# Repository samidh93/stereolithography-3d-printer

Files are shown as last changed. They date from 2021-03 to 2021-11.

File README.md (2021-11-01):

# stereolithography 3d printer

## description

SLA 3d printer was created and developped during this project.
The main goal is to print a cylindre using a resonant laser system.
in this repo you will find:
- software stack written in c on stm32 microcontroller [main](/Src/main.c)
- pcb designed with eagle [pcb](pcb_eagle/)
- documentation and contributions [report](3D%20Drucker_Reser12_V5.pdf)

## Picture from inside the printer 
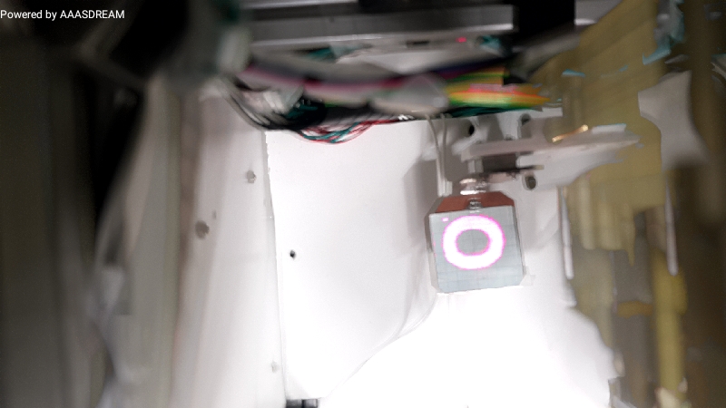
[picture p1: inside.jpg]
inside


## picture from outside the printer
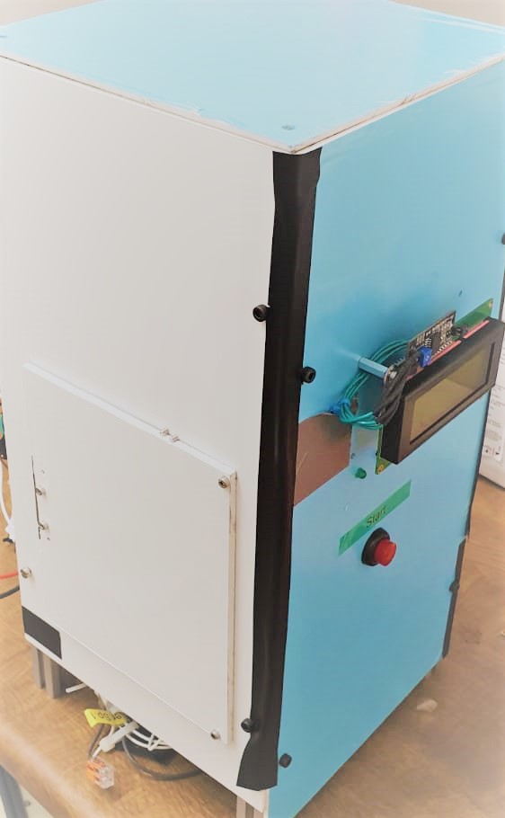
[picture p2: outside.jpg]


## demonstartion of running
running demo

[running mp4 ideo with sound](running.mp4)

## demonstartion of printing
printing demo

[printing mp4 video with sound](printing.mp4)

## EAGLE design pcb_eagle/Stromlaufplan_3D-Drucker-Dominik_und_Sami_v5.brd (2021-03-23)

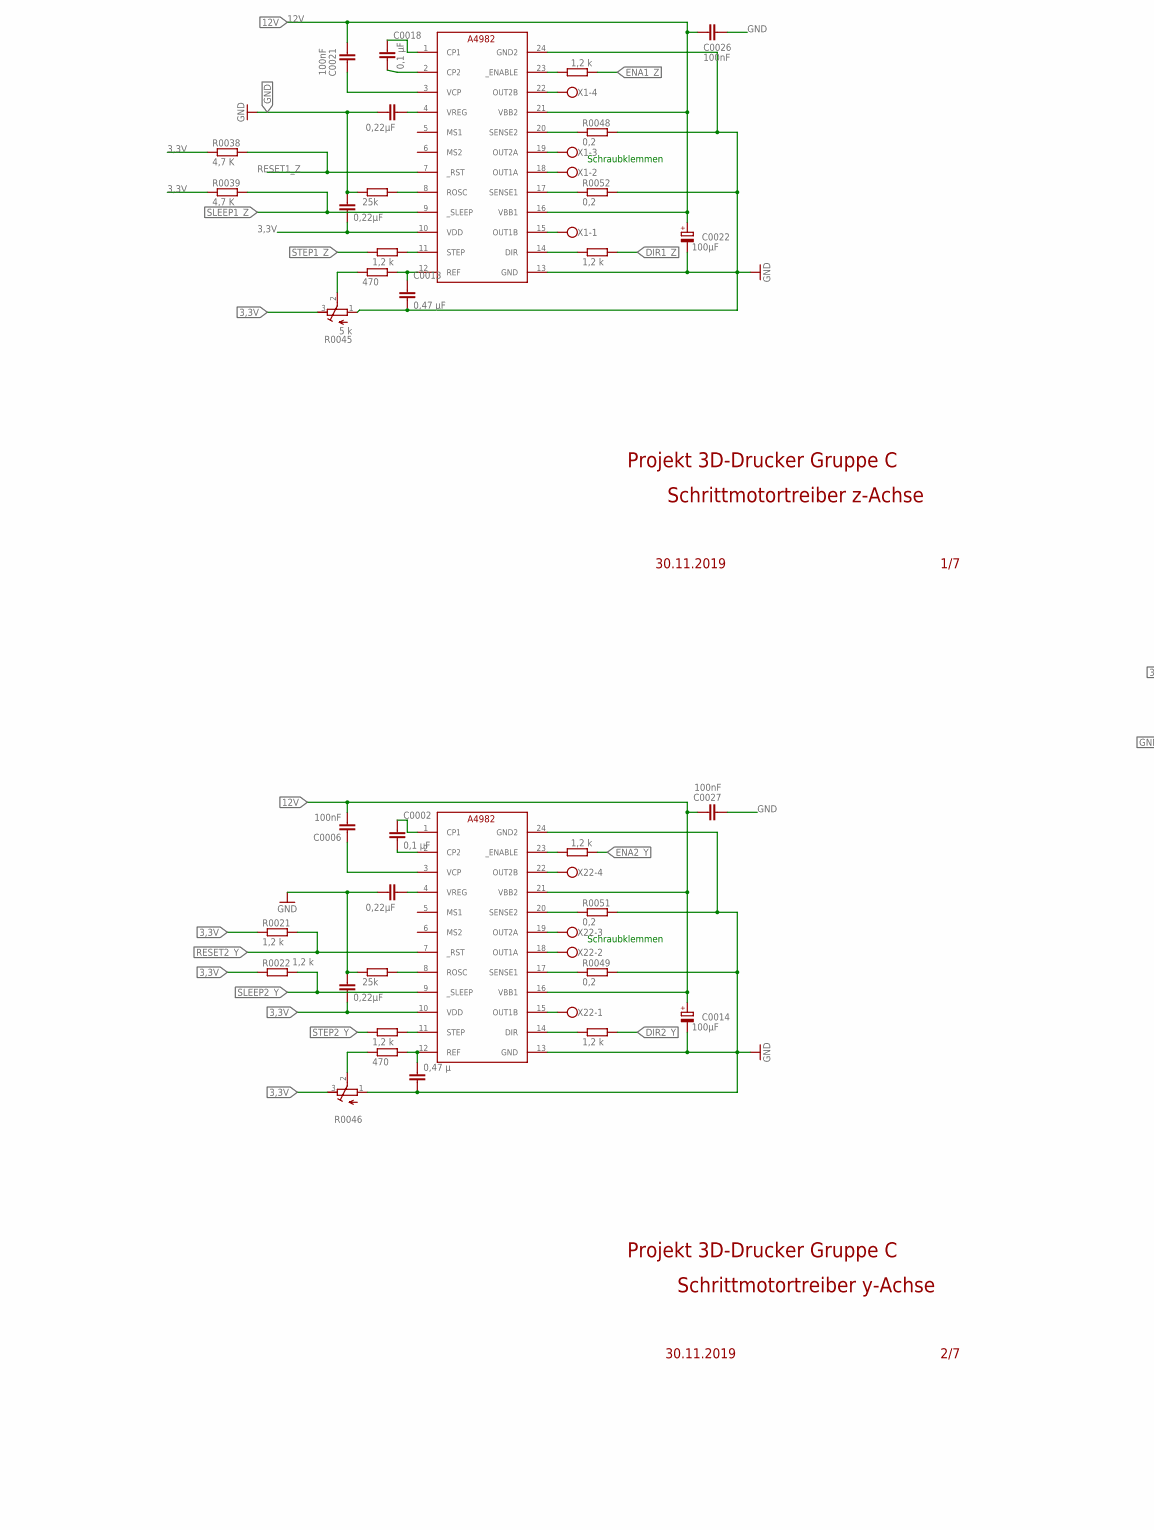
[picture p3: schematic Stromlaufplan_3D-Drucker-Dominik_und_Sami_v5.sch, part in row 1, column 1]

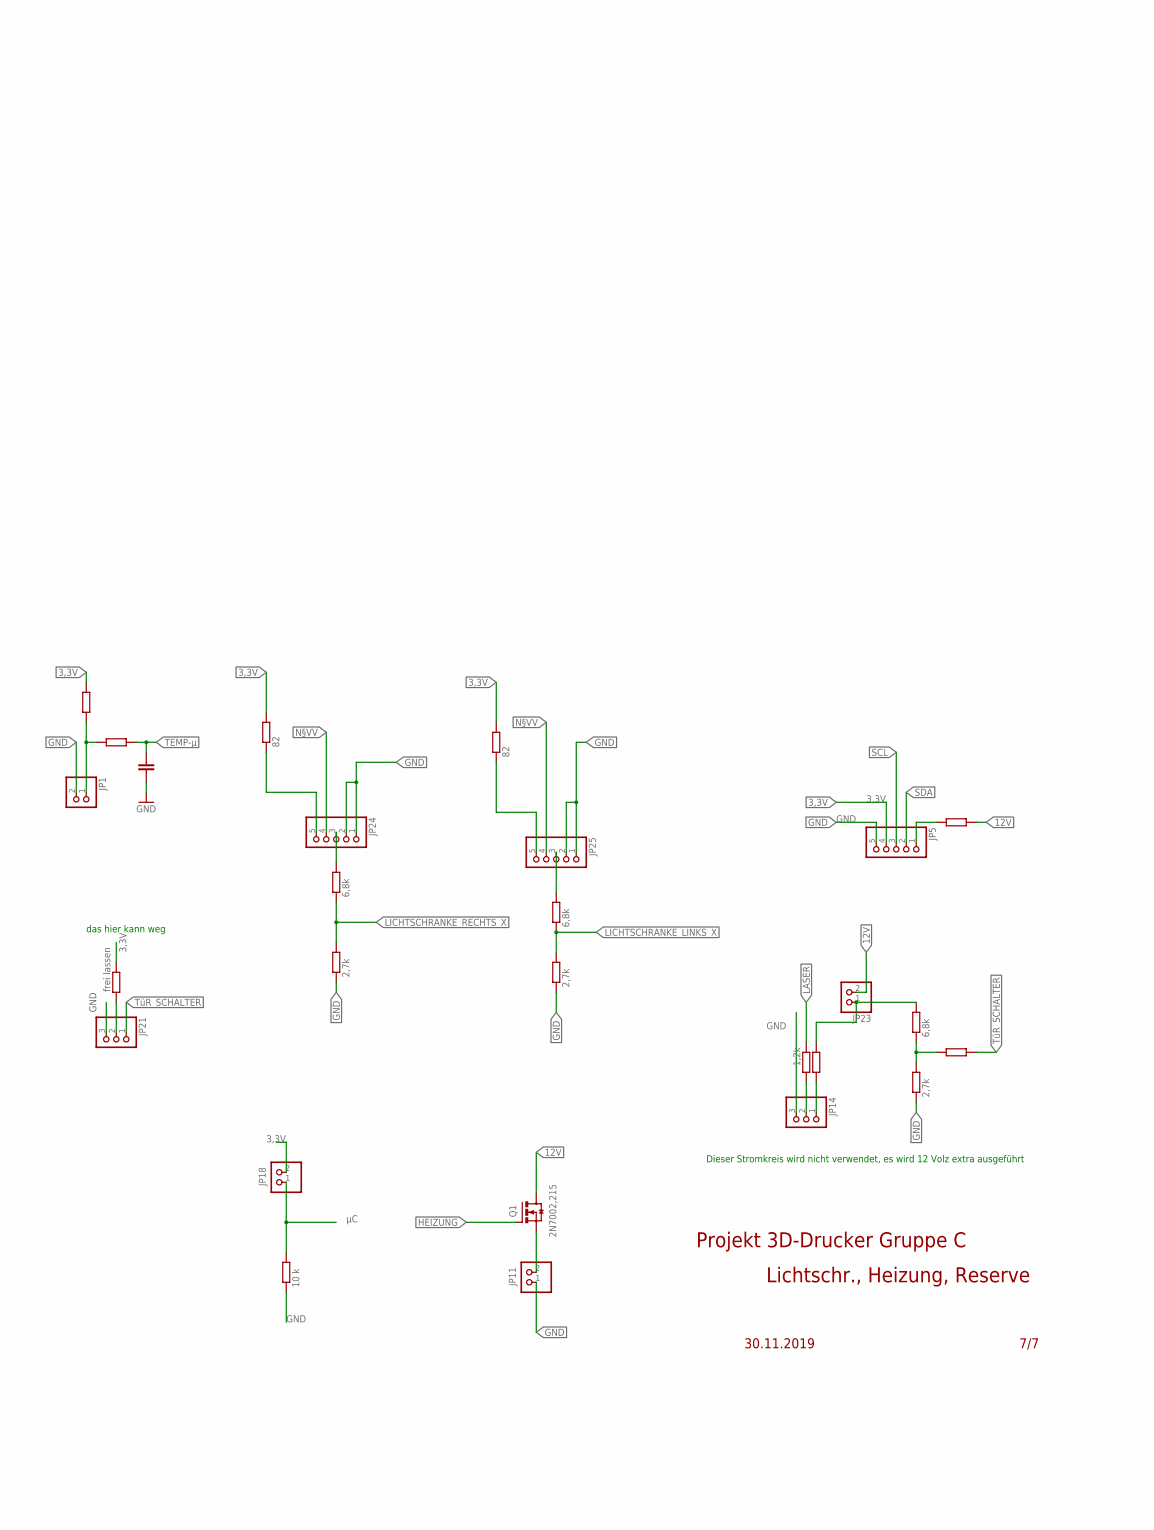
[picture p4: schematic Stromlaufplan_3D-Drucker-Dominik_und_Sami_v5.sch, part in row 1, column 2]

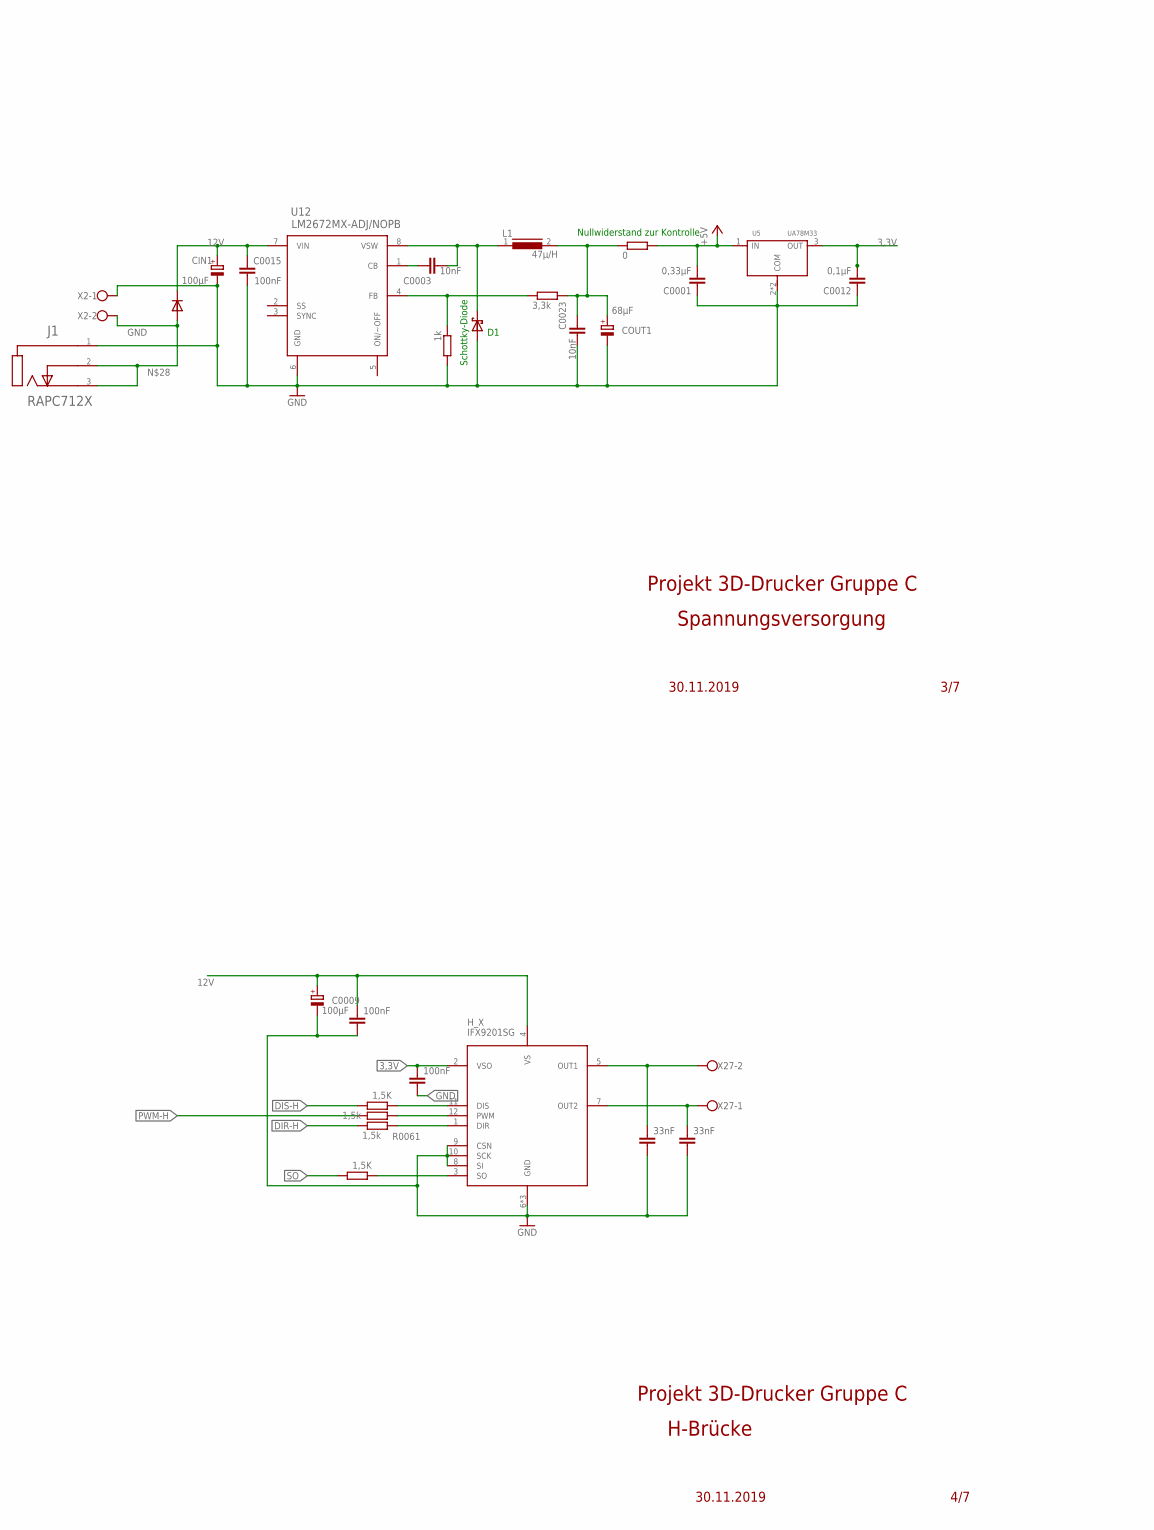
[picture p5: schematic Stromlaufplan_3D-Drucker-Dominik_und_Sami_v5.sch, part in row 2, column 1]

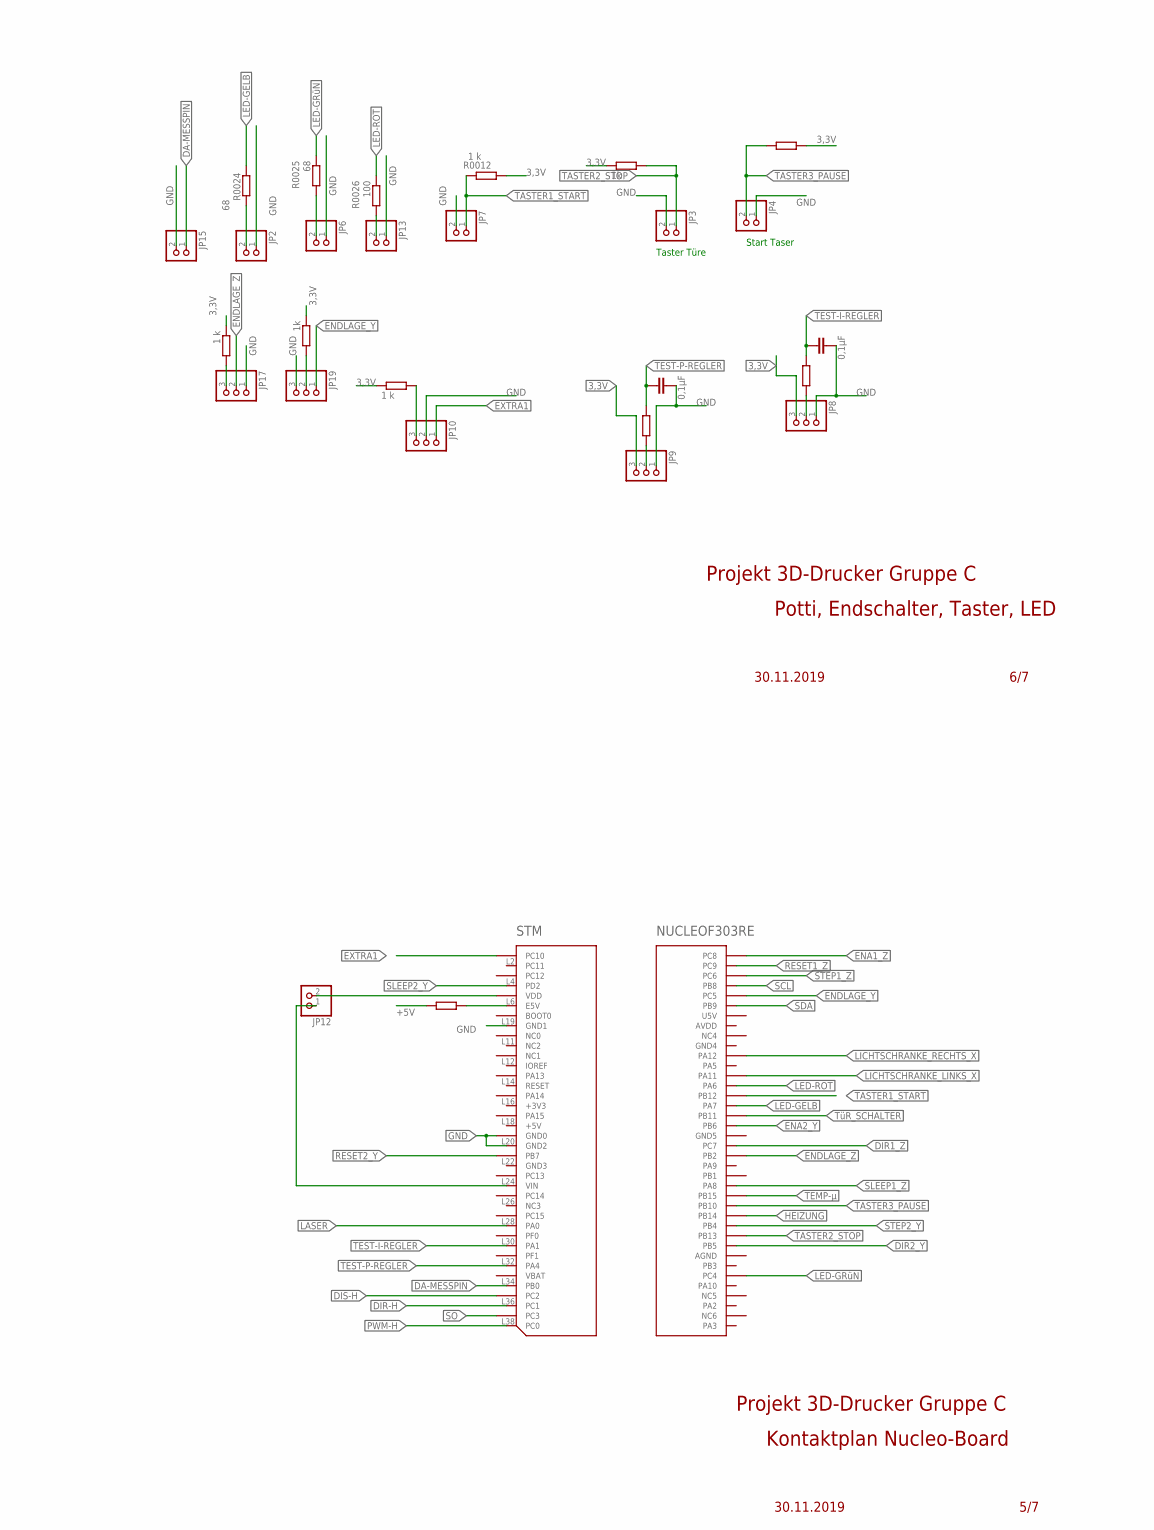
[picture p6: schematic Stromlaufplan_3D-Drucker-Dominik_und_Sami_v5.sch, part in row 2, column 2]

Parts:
A4982_Y, A4982_Y1: A4982_STEPDRIVER; TSSOP24
C0001: 0,33µF; C0603
C0002, C0018: 0,1 µF; C0603
C0003, C0023: 10nF; C0603
C0004, C0005, C0019, C0020: 0,22µF; C0603
C0006, C0015, C0021, C0026, C0027: 100nF; C0603
C0007, C0008: 33nF; C0805
C0009, C0014, C0022: 100µF; UD-8X10_NICHICON
C0010: 0,47 µ; C0805
C0011: C-EUC0805; C0805
C0012, C0024, C0025: 0,1µF; C0603
C0013: 0,47 µF; C0603
C0016, C0041: 100nF; C0805
CIN1: 100µF; 140CLH-1010
COUT1: 68µF; 140CLH-1010
D1: 1N5819HW-7-F; SOD-123_MINI-SMA
D12: MURS360BT3G; SMB
H_X: IFX9201SG; BSOP-12
J1: RAPC712X; SWC_RAPC712X
JP1, JP2, JP3, JP4, JP6, JP7, JP11, JP12, JP13, JP15, JP18, JP23: PINHD-1X2; 1X02
JP5, JP24, JP25: PINHD-1X5; 1X05
JP8, JP9, JP10, JP14, JP17, JP19, JP21: PINHD-1X3; 1X03
L1: 47µ/H; INDUCTOR
Q1: 2N7002,215; SOT23-3
R0001, R0063: 1,5K; R0603
R0002, R0005, R0043: 6,8k; R0603
R0003, R0013: 1k; R0603
R0004, R0028, R0044: 2,7k; R0603
R0006, R0019: 25k; R0603
R0007: 10 k; R0603
R0008, R0014, R0016, R0017, R0020, R0027, R0030, R0031, R0053: R-EU_R0603; R0603
R0009, R0010, R0011, R0021, R0022, R0034, R0035, R0036: 1,2 k; R0603
R0012, R0015, R0033: 1 k; R0603
R0018: frei lassen; R0603
R0023, R0037: 470; R0603
R0024, R0025: 68; R0603
R0026: 100; R0603
R0029, R0032: 82; R0603
R0038, R0039: 4,7 K; R0603
R0042: 1,2k; R0603
R0045: 5 k; RTRIM3296Y
R0046: R-TRIMM3296Y; RTRIM3296Y
R0048, R0049, R0051, R0052: 0,2; R2512
R0061, R0062: 1,5k; R0603
STM: NUCLEOF303RE; DIL40
TEST_R: 0; R0603
TEST_R2: 3,3k; R0603
TEST_R3: 1k; R0603
U5: UA78M33; SOT-223
U12: LM2672MX-ADJ/NOPB; SOIC-8
X1, X22: SCHRAUBKLEMME_4X; W237-4
X2, X27: SCHRAUBKLEMME_2X; W237-102

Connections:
3,3V: A4982_Y.10 (VDD), A4982_Y1.10 (VDD), C0005.1, C0012.2, C0016.1, C0020.1, H_X.2 (VSO), JP5.4, JP8.3, JP9.3, JP18.2, R0003.1, R0008.1, R0012.1, R0013.1, R0014.1, R0015.1, R0018.1, R0021.1, R0022.1, R0029.2, R0032.2, R0033.1, R0038.1, R0039.1, R0045.3 (E), R0046.3 (E), U5.3 (OUT)
12V: A4982_Y.16 (VBB1), A4982_Y.21 (VBB2), A4982_Y1.16 (VBB1), A4982_Y1.21 (VBB2), C0006.2, C0009.+, C0014.+, C0015.2, C0021.2, C0022.+, C0026.2, C0027.1, C0041.1, CIN1.+, D12.1, H_X.4 (VS), JP14.1, JP23.2, Q1.3 (D), R0016.2, R0030.2, U12.7 (VIN)
+5V: C0001.2, R0027.1, TEST_R.2, U5.1 (IN)
DA-MESSPIN: JP15.1, STM.L34 (PB0)
DIR1_Z: R0036.2, STM.R19 (PC7)
DIR2_Y: R0011.2, STM.R29 (PB5)
DIR-H: R0061.1, STM.L36 (PC1)
DIS-H: R0063.1, STM.L35 (PC2)
ENA1_Z: R0034.1, STM.R2 (PC8)
ENA2_Y: R0009.1, STM.R17 (PB6)
ENDLAGE_Y: JP19.1, STM.R6 (PC5)
ENDLAGE_Z: JP17.2, STM.R22 (PB2)
EXTRA1: JP10.1, STM.L1 (PC10)
GND: A4982_Y.13 (GND), A4982_Y.24 (GND2), A4982_Y1.13 (GND), A4982_Y1.24 (GND2), C0001.1, C0004.2, C0005.2, C0007.2, C0008.2, C0009.-, C0010.2, C0011.2, C0012.1, C0013.2, C0014.-, C0015.1, C0016.2, C0019.2, C0020.2, C0022.-, C0023.2, C0024.1, C0025.1, C0026.1, C0027.2, C0041.2, CIN1.-, COUT1.-, D1.A, H_X.6 (GND), H_X.8 (SI), H_X.9 (CSN), H_X.10 (SCK), H_X.PAD (GND), H_X.PAD2 (GND), J1.1 (CENTER_PIN), JP1.2, JP2.1, JP3.2, JP4.1, JP5.5, JP6.1, JP7.2, JP8.1, JP9.1, JP10.2, JP11.1, JP13.1, JP14.3, JP15.2, JP17.1, JP19.3, JP21.3, JP24.1, JP24.2, JP25.1, JP25.2, R0004.1, R0006.1, R0007.1, R0019.1, R0028.1, R0044.1, R0045.1 (A), R0046.1 (A), R0048.2, R0049.2, R0051.2, R0052.2, STM.L8 (GND0), STM.L19 (GND1), STM.L20 (GND2), TEST_R3.2, U5.2 (COM), U5.TER (COM), U12.6 (GND), X2.1
HEIZUNG: Q1.1 (G), STM.R28 (PB14)
LASER: R0042.1, STM.L28 (PA0)
LED-GELB: R0024.2, STM.R15 (PA7)
LED-GRüN: R0025.1, STM.R34 (PC4)
LED-ROT: R0026.1, STM.R13 (PA6)
LICHTSCHRANKE_LINKS_X: R0005.1, R0028.2, STM.R14 (PA11)
LICHTSCHRANKE_RECHTS_X: R0002.1, R0004.2, STM.R12 (PA12)
unnamed: A4982_Y1.2 (CP2), C0018.2
unnamed: JP17.3, R0015.2
unnamed: JP24.5, R0029.1
unnamed: R0023.1, R0046.2 (S)
unnamed: C0003.1, U12.1 (CB)
unnamed: JP2.2, R0024.1
unnamed: A4982_Y.12 (REF), C0010.1, R0023.2
unnamed: A4982_Y.2 (CP2), C0002.2
unnamed: A4982_Y.1 (CP1), C0002.1
unnamed: A4982_Y.3 (VCP), C0006.1
unnamed: JP19.2, R0003.2
unnamed: A4982_Y.4 (VREG), C0004.1
unnamed: A4982_Y1.12 (REF), C0013.1, R0037.2
unnamed: A4982_Y1.1 (CP1), C0018.1
unnamed: A4982_Y.18 (OUT1A), X22.2
unnamed: A4982_Y.15 (OUT1B), X22.1
unnamed: A4982_Y.19 (OUT2A), X22.3
unnamed: A4982_Y.22 (OUT2B), X22.4
unnamed: A4982_Y.17 (SENSE1), R0049.1
unnamed: A4982_Y.20 (SENSE2), R0051.1
unnamed: A4982_Y.8 (ROSC), R0006.2
unnamed: A4982_Y.23 (_ENABLE), R0009.2
unnamed: H_X.3 (SO), R0001.2
unnamed: A4982_Y.14 (DIR), R0011.1
unnamed: A4982_Y1.4 (VREG), C0019.1
unnamed: A4982_Y1.15 (OUT1B), X1.1
unnamed: JP23.1, R0016.1, R0043.2
unnamed: D12.2, J1.2 (SHUNT), J1.3 (SLEEVE), X2.2
unnamed: C0023.1, COUT1.+, L1.2, TEST_R.1, TEST_R2.2
unnamed: A4982_Y1.19 (OUT2A), X1.3
unnamed: C0003.2, D1.C, L1.1, U12.8 (VSW)
unnamed: JP9.2, R0031.1
unnamed: JP24.3, R0002.2
unnamed: JP25.3, R0005.2
unnamed: R0017.1, R0043.1, R0044.2
unnamed: JP8.2, R0053.1
unnamed: A4982_Y1.22 (OUT2B), X1.4
unnamed: JP11.2, Q1.2 (S)
unnamed: A4982_Y1.17 (SENSE1), R0052.1
unnamed: JP6.2, R0025.2
unnamed: JP13.2, R0026.2
unnamed: A4982_Y1.20 (SENSE2), R0048.1
unnamed: A4982_Y1.8 (ROSC), R0019.2
unnamed: A4982_Y1.23 (_ENABLE), R0034.2
unnamed: H_X.1 (DIR), R0061.2
unnamed: H_X.12 (PWM), R0062.2
unnamed: C0007.1, H_X.5 (OUT1), X27.2
unnamed: JP5.1, R0030.1
unnamed: A4982_Y1.14 (DIR), R0036.1
unnamed: JP25.5, R0032.1
unnamed: JP10.3, R0033.2
unnamed: JP14.2, R0042.2
unnamed: JP1.1, R0008.2, R0020.2
unnamed: A4982_Y1.18 (OUT1A), X1.2
unnamed: A4982_Y1.3 (VCP), C0021.1
unnamed: JP12.2, STM.L5 (VDD)
unnamed: R0037.1, R0045.2 (S)
unnamed: JP12.1, STM.L24 (VIN)
unnamed: R0027.2, STM.L6 (E5V)
unnamed: JP21.2, R0018.2
unnamed: H_X.11 (DIS), R0063.2
unnamed: C0008.1, H_X.7 (OUT2), X27.1
N§VV: JP24.4, JP25.4, TEST_R2.1, TEST_R3.1, U12.4 (FB)
PWM-H: R0062.1, STM.L38 (PC0)
RESET1_Z: A4982_Y1.7 (_RST), R0038.2, STM.R1 (PC9)
RESET2_Y: A4982_Y.7 (_RST), R0021.2, STM.L21 (PB7)
SCL: JP5.3, STM.R3 (PB8)
SDA: JP5.2, STM.R5 (PB9)
SLEEP1_Z: A4982_Y1.9 (_SLEEP), R0039.2, STM.R23 (PA8)
SLEEP2_Y: A4982_Y.9 (_SLEEP), R0022.2, STM.L4 (PD2)
SO: R0001.1, STM.L37 (PC3)
STEP1_Z: R0035.1, STM.R4 (PC6)
STEP2_Y: R0010.1, STM.R27 (PB4)
STP1: A4982_Y.11 (STEP), R0010.2
STP2: A4982_Y1.11 (STEP), R0035.2
TASTER1_START: JP7.1, R0012.2, STM.R16 (PB12)
TASTER2_STOP: JP3.1, R0013.2, STM.R30 (PB13)
TASTER3_PAUSE: JP4.2, R0014.2, STM.R25 (PB10)
TEMP-µ: C0011.1, R0020.1, STM.R26 (PB15)
TEST-I-REGLER: C0025.2, R0053.2, STM.L30 (PA1)
TEST-P-REGLER: C0024.2, R0031.2, STM.L32 (PA4)
TüR_SCHALTER: JP21.1, R0017.2, STM.R18 (PB11)
µC: JP18.1, R0007.2

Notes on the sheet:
Nullwiderstand zur Kontrolle
Schraubklemmen
das hier kann weg
Schottky-Diode
Dieser Stromkreis wird nicht verwendet, es wird 12 Volz extra ausgeführt
Start Taser
Taster Türe
Schrittmotortreiber z-Achse
1/7
Schrittmotortreiber y-Achse
Spannungsversorgung
H-Brücke
Kontaktplan Nucleo-Board
Potti, Endschalter, Taster, LED
Lichtschr., Heizung, Reserve
2/7
3/7
5/7
6/7
7/7
4/7
Projekt 3D-Drucker Gruppe C
30.11.2019

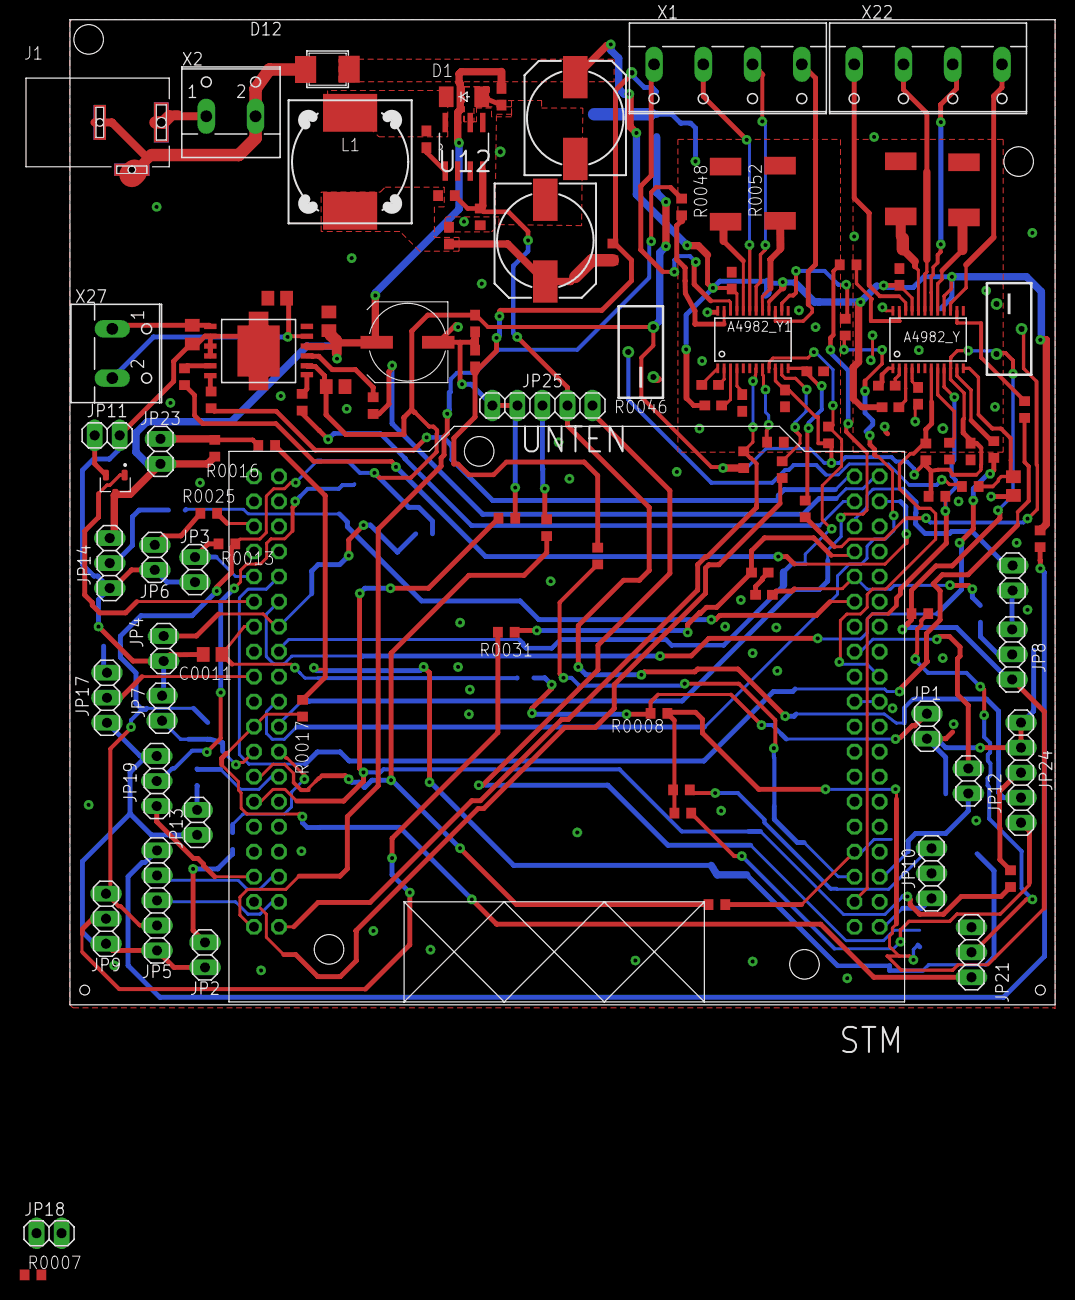
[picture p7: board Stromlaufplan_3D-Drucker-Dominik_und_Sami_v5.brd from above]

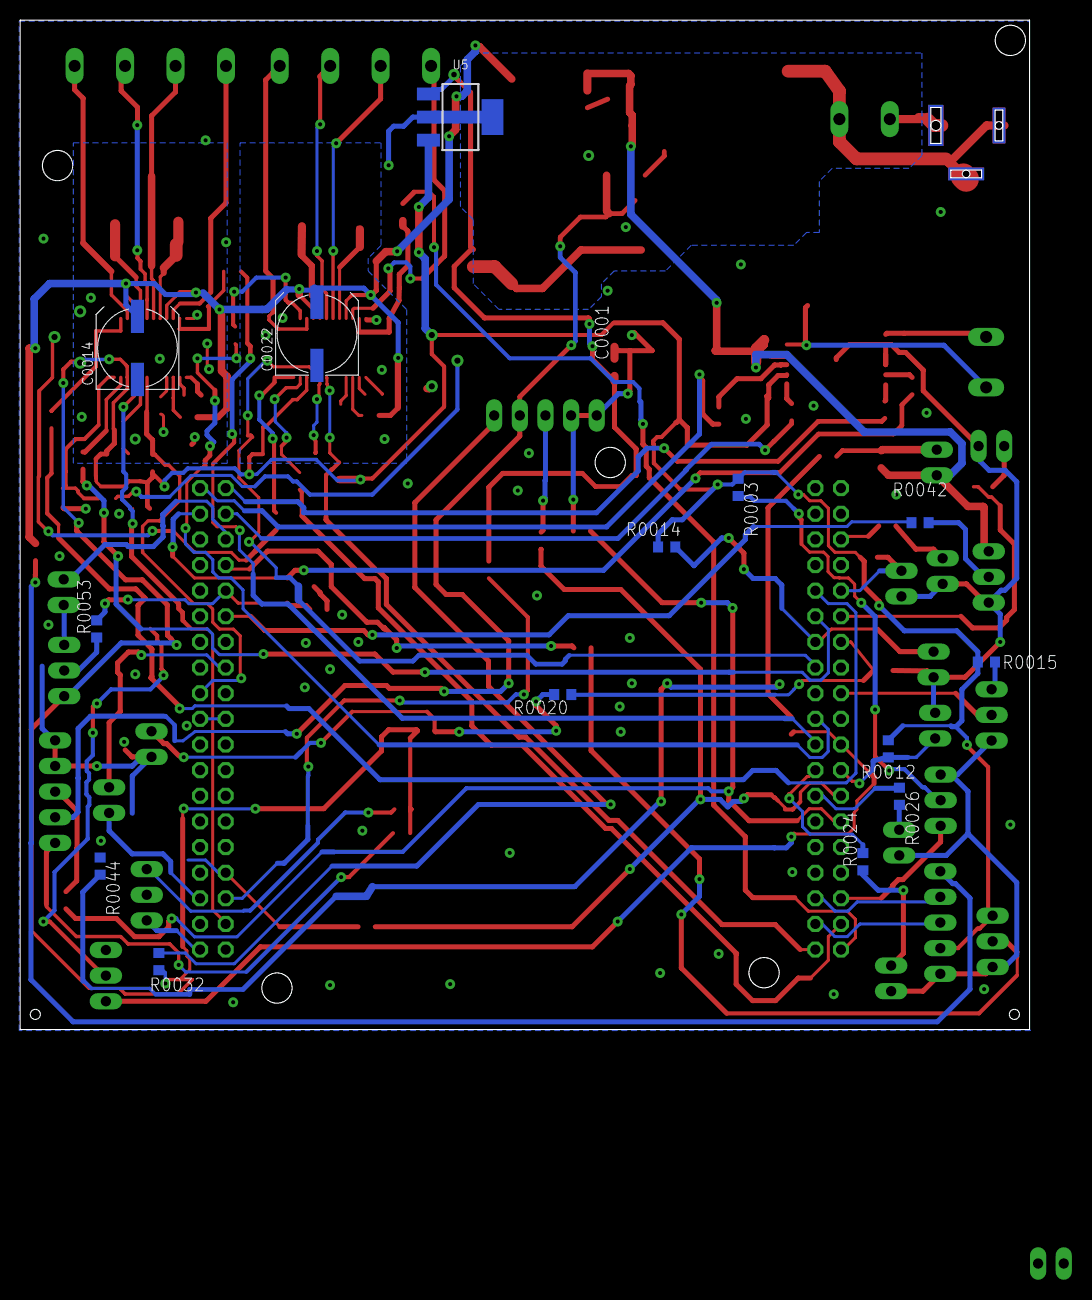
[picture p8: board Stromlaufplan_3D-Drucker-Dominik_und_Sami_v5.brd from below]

Board: 2 copper layers, 100.0 x 100.0 mm, 121 parts (14 on the bottom side), 104 nets.

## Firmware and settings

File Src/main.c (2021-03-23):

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

/* Includes ------------------------------------------------------------------*/
#include "main.h"

/* USER CODE BEGIN Includes */

#include "stdio.h"
#include "stdlib.h"
#include "math.h"						//Include math bibliothek
#include "SchrittMotor_Y.h"				//Bibliothek der treiber Y_achse
#include "SchrittMotor_Z.h"				//Bibliothek der treiber Z_achse
#include "print_scan_usart2.h"			//Bibliothek zur ausgabe von werte durch printf via uart
#include "i2c-lcd.h"					//Dispaly Bibliothek
#include "IIR_1_Order.h"				//IIR filetr bibliothek
//#include "Delay_Mikro_Sekunde.h"

/* USER CODE END Includes */

/* USER CODE BEGIN PTD */
typedef enum { Start, Init, Drucken, Ende} States_t;
/* USER CODE END PTD */

ADC_HandleTypeDef hadc1;
ADC_HandleTypeDef hadc2;
ADC_HandleTypeDef hadc3;
ADC_HandleTypeDef hadc4;
DMA_HandleTypeDef hdma_adc4;

I2C_HandleTypeDef hi2c1;

TIM_HandleTypeDef htim1;
TIM_HandleTypeDef htim2;
TIM_HandleTypeDef htim3;
TIM_HandleTypeDef htim4;
TIM_HandleTypeDef htim6;
TIM_HandleTypeDef htim7;
TIM_HandleTypeDef htim8;
TIM_HandleTypeDef htim15;
TIM_HandleTypeDef htim16;
TIM_HandleTypeDef htim17;

UART_HandleTypeDef huart2;

/* USER CODE BEGIN PV */
/******************************************************************
 * *************************User_Variablen*************************
 * ****************************************************************/

/*******************************Variablen Sinus Tabelle*************************/
float pi = 3.1416f;						// Variable pi
float sinus [128];						// Array für Sinustabelle
float ZeitProSchwingung;				//zeit für 1 schwingung
float remainTime;						//verbleibende zeit
/**************************Zeit variablen Lichtschranke***************************/
volatile float t_1 = 0;						// Zeitpunkt erste fallende Flanke
volatile float t_2 = 0;						// Zeitpunkt zweite steigende Flanke
volatile float t_3 = 0;						// Zeitpunkt zweite fallende Flanke
volatile float t_4 = 0;						// Zeitpunkt dritte steigende Flanke
volatile float hell_1 = 0;					// bereich in dem wir belichten 1/3 der zeit(_1 bedeutet fur halbe schwingung nach rechts)
volatile float hell_2 = 0;					// bereich in dem wir belichten 1/3 der zeit(_2 bedeutet fur halbe schwingung nach links)
volatile float dunkel_1 = 0;					// bereich in dem wir nicht belichten(_1 bedeutet fur halbe schwingung nach rechts)
volatile float dunkel_2 = 0;					// bereich in dem wir nicht belichten(_2 bedeutet fur halbe schwingung nach links)
volatile float dunkel_1_90P = 0;				// Dunkel_1 bereich mit offset
volatile float dunkel_2_90P = 0;				// Dunkel_2 bereich mit offset

/*********************Variablen Amplitude Regler**************************/
volatile float frequenz_soll = 8.34f;				// Sollfrequenz  --> muss für bbeide LAser jeweils angepasst werden
volatile float frequenz_gemessen = 0;				// gemessene Frequenz
volatile float kdc = 0.25f;					// Vorfaktor für duty cycle in Sinustabelle
volatile float Toleranz_Regler = 0.5f;				// toleranz faktor pi regler

volatile float e = 0; 						// aktuelle Regelabweichung pro Iteration
volatile float esum = 0; 					// Aufsummierung Regelabweicuhung
volatile float kp = 0.8; 					// P-Anteil des Reglers
volatile float ki = 0.06f;					// I-Anteil des Reglers
volatile float kdc_max = 0.25f;					// Maximaler Vorfaktor von 0,25 (25%)
volatile float kdc_min = 0.1;					//Minimaler kdc-Wert des Programms
volatile float faktor_psc = 327272.72f;				// Faktor für psc zum Bestimmen der gemessenen Frequenz
volatile float verhaeltnis_soll= 0.6f;				// Fuhrungsgroße
volatile float verhaeltnis;  					// Verhaltnis Hell zu Dunkel

/******************************Zustände und Flags***********************************************/
volatile int zustand = 0;					// Zustands variable für case-Funktion der Lichtschranke
volatile int flag_schr_z =0;					// Für was sind diese flags?
volatile _Bool flag_schr_y = 0;					// flag für interrupt um die y achse zu bewegen
volatile _Bool ref_y = 0;					// Refernz der y-Achse
volatile _Bool ref_z = 0;					// Refernz der z-Achse
volatile _Bool ist_geschwungen = 0;				// Flag für wie viele schwingung sind gemacht
volatile int Anzahl_Schwingung = 0;				// Zähler fur anzahl der schwingung, parameter für regeleung
volatile int Anzahl_Ebenen = 0;
volatile _Bool Doorstate =0;					// Endschalter an Türe geschlossen?
volatile _Bool Start_Taster_gedruckt = 0;			// Damit Taster nicht zufällig Wert 1 enthält
//volatile _Bool Init = 0;
//volatile _Bool Start = 0;
//volatile _Bool Drucken = 0;
//volatile _Bool Ende = 0;
volatile _Bool Schalter_geschlossen = 0;


/***************************Zähler variablen****************************************************/
volatile int32_t zaehler_schr_y = 0;			//zähler für schritt der y achse
volatile int32_t zaehler = 0;				// Variable für das Abschreiben der Sinustabelle
volatile int32_t zaehler_X = 0;				//zahler für 250 abtasten der x achse  / Ich glaub das sind jetzt 280 oder so?
volatile int32_t zaehler_Y = 0;				//zahler für 250 abtasten der y achse
volatile int32_t Ebenerunter = 0;


/**************************Variablen kreis Berechnung****************************************/
volatile float xm = 124.5; 					// Mittelpunkt x
volatile float ym = 124.5;					// Mittelpunkt y
volatile float dx; 						// aktueller x-Achsen Abstand von aktuellem Punkt zu Mittelpunkt
volatile float dy;						// aktueller y-Achsen Abstand von aktuellem Punkt zu Mittelpunkt
volatile float dxy;						// Abstand yum Mittelpunkt (Ist dannn der spätere Betrag aus a² und b²)
float X_Achse[250];						// Array für x_Achse mit 250 Abfragen
//uint8_t ZweiD_Array[250][250] = {0};				// test array 50*50 (nicht verwendet)


/**********************Temperature Variablen*****************************************/
double tempReading;
float tempF;
double tempK;
float tempC;
_Bool Polymerready = 0;
uint32_t adc_buf[1];
double temp;
/************************Entprellen***************************************************/
_Bool ledState = SET;
_Bool buttonState;
_Bool lastButtonState = RESET;
int lastDebounceTime = 0;
int debounceDelay = 50;
int reading;
/***********************Extra**********************************************************/
float inkrement = (120/280);
float bogen_120 = 2.094395102;


/*
//IMPERIAL_MARCH
int	C8	=	17199	;
int	B7	=	18222	;
int	AB7	=	19306	;
int	A7	=	20454	;
int	GA7	=	21670	;
int	G7	=	22958	;
int	FG7	=	24324	;
int	F7	=	25770	;
int	E7	=	27303	;
int	DE7	=	28926	;
int	D7	=	30646	;
int	CD7	=	32469	;
int	C7	=	34399	;
int	B6	=	36445	;
int	AB6	=	38612	;
int	A6	=	40908	;
int	GA6	=	43341	;
int	G6	=	45918	;
int	FG6	=	48648	;
int	F6	=	51541	;
int	E6	=	54606	;
int	DE6	=	57853	;
int	D6	=	61293	;
int	CD6	=	64938	;
 */


/* USER CODE END PV */

void SystemClock_Config(void);
static void MX_GPIO_Init(void);
static void MX_ADC1_Init(void);
static void MX_ADC2_Init(void);
static void MX_ADC3_Init(void);
static void MX_ADC4_Init(void);
static void MX_I2C1_Init(void);
static void MX_TIM1_Init(void);
static void MX_TIM2_Init(void);
static void MX_TIM3_Init(void);
static void MX_TIM4_Init(void);
static void MX_TIM15_Init(void);
static void MX_TIM16_Init(void);
static void MX_USART2_UART_Init(void);
static void MX_TIM7_Init(void);
static void MX_TIM6_Init(void);
static void MX_TIM8_Init(void);
static void MX_TIM17_Init(void);
static void MX_DMA_Init(void);
/* USER CODE BEGIN PFP */
//static void state_machine(void);


/* USER CODE END PFP */

/* USER CODE BEGIN 0 */


/******************************************************************
 * *************************User_Funktionen_Definition*************************
 * ****************************************************************/


/*************************Delay in mikrosekunde***********************************/

void delay_us(uint16_t us)						//delay in µs
{
	__HAL_TIM_SET_COUNTER(&htim8,0);				//Timer8; Counter auf 0 setzen
	while (__HAL_TIM_GET_COUNTER(&htim8) < us);			//wenn das counter wert kleiner als gewunschte delay
}

/**********************Sinus Erzeugung*********************************************/
void generate_sinus()
{
	for(int i=0; i<128; i++)		//sinus tabelle auffulen für 128 werte
	{
		sinus [i] = sinf(pi*i/128);
	}
}

/******************2 dimensional Array für den Kreis***********************************/
/*void Kreis_berechnen()
{
	static uint8_t i;

	for(i=0; i<250; i++)					//for schleife der berechnung kreis punkte
	{
		dx = (i-xm);							//hier abs für postive werte
		dy = (zaehler_250_Y-ym);
		dxy = sqrtf((dx*dx)+(dy*dy));
		if ((dxy <= 120)&&(dxy >= 115))
		{
			X_Achse [i] = 1;

		}
		else
		{
			X_Achse [i] = 0;
		}
	}
}*/
/*************************Referenzfahrt y_achse********************************/

void home_y_achse()
{
	// Initialisierung Y_achse
	HAL_GPIO_WritePin(GPIOB, GPIO_PIN_7, GPIO_PIN_SET);			// Reset (inverted) PIN
	HAL_GPIO_WritePin(GPIOD, GPIO_PIN_2, GPIO_PIN_SET);			// Sleep (inverted) PIN
	HAL_GPIO_WritePin(GPIOB, GPIO_PIN_6, GPIO_PIN_RESET); 			// Enable (inverted) PIN

	// Referenzier Y-Achse
	HAL_GPIO_WritePin(GPIOB, GPIO_PIN_5, GPIO_PIN_RESET);			// Direction Pin Reset (-sense rotation)
	do									// Mache Anweisung, während Pin Endschalter (PC5) gleich 1 ist (da Öffner)
	{
		HAL_GPIO_WritePin(GPIOB, GPIO_PIN_4, GPIO_PIN_SET);		// STEP PIN High
		delay_us(700);
		HAL_GPIO_WritePin(GPIOB, GPIO_PIN_4, GPIO_PIN_RESET);		// STEP PIN Low
		delay_us(700);
	}
	while (HAL_GPIO_ReadPin(GPIOC, GPIO_PIN_5) == 1); 			// wenn gpio pin ist pin endlage y schalter betatigt



	// Dann fahre wieder von Endschalter weg zu Startposition für Druck

	HAL_GPIO_WritePin(GPIOB, GPIO_PIN_5,SET);				// Dazu wird Direction Pin umgedreht (auf set)

	for(int i=0; i<400; i++)						// Rotation Schleife Y_achse 500 Schritte = 10 mm
	{
		HAL_GPIO_WritePin(GPIOB, GPIO_PIN_4, GPIO_PIN_SET);		// STEP PIN High
		delay_us(700);
		HAL_GPIO_WritePin(GPIOB, GPIO_PIN_4, GPIO_PIN_RESET);		// STEP PIN Low
		delay_us(700);
	}
	ref_y=1;								// Variable stellt dar, dass Referenzfahrt abgeschlossen wurde
}



/*************************Referenzfahrt_Z_achse********************************/


void home_z_achse()
{

	HAL_TIM_Base_Start(&htim8);					//Delay in mikrosekunde timer start

	// Initialisierung z-Achse

	HAL_GPIO_WritePin(GPIOC, GPIO_PIN_9, GPIO_PIN_SET);			// Reset (inverted) PIN
	HAL_GPIO_WritePin(GPIOA, GPIO_PIN_8, GPIO_PIN_SET);			// Sleep (inverted) PIN
	HAL_GPIO_WritePin(GPIOC, GPIO_PIN_8, GPIO_PIN_RESET); 			// Enable (inverted) PIN


	// Rotation Schleife: z-Achse ganz unten und dann bis end schalter

	HAL_GPIO_WritePin(GPIOC, GPIO_PIN_7, GPIO_PIN_RESET);   		//  Direction Pin (+sense rotation) nach oben
	do									// do this while condition ist true
	{
		HAL_GPIO_WritePin(GPIOC, GPIO_PIN_6, GPIO_PIN_SET);		// STEP PIN High
		delay_us(700);
		HAL_GPIO_WritePin(GPIOC, GPIO_PIN_6, GPIO_PIN_RESET);		// STEP PIN Low
		delay_us(700);
	}
	while (HAL_GPIO_ReadPin(GPIOB, GPIO_PIN_2) == 0); 			// wenn gpio pin ist pin endlage z schalter betätigt (Endschalter als Schließer ausgeführt, da Öffnerkontakt kaputt)

	HAL_GPIO_WritePin(GPIOC, GPIO_PIN_7,GPIO_PIN_SET);			//  Direction Pin set (-sense rotation) nach unten

	for(int i=0; i<1500; i++)						// Rotation Schleife Z_achse 20 Schritte sind 0,1 mm
	{
		HAL_GPIO_WritePin(GPIOC, GPIO_PIN_6, GPIO_PIN_SET);		// STEP PIN High
		delay_us(700);
		HAL_GPIO_WritePin(GPIOC, GPIO_PIN_6, GPIO_PIN_RESET);		// STEP PIN Low
		delay_us(700);
	}
	ref_z=1;								// Referenzfaht
}


/*************************************Schrittmotor_Y_Achse_Bewegen_schritte******************************/

//Funktion zum Bewegen der y-Achse während Druckvorgang:


void Schrittmotor_y_achse_bewegen()
//Ablauf: Wenn Flag gesetzt und bereits über 20 Schwingungen erledigt, dann verfahren y-Achse um 20 Schritte
{
	if ((flag_schr_y == 1) && (Anzahl_Schwingung >= 20))			// wenn flag schrittmotor y-Achse = 1 und Schwinger ist breits 20 mal geschwungen
	{
		zaehler_schr_y++;						// Zählt Koordinate der y-Achse

		for(int i=0; i<20; i++)						// 20 Schritte fahren
		{
			HAL_GPIO_WritePin(GPIOB, GPIO_PIN_4, GPIO_PIN_SET);	// STEP PIN High
			delay_us(1000);
			HAL_GPIO_WritePin(GPIOB, GPIO_PIN_4, GPIO_PIN_RESET);	// STEP PIN Low
			delay_us(1000);
		}

		//Funktion: Wenn y-Koordinate den Wert 250 erreicht hat, soll die Drehrichtung des Schrittmotors umgedreht werden
		int position_schr_y = zaehler_schr_y%250;			// Man teilt das aktuelle Feld immer durch 250 (zb. 50 durch 250; 100 durch 250;..). Man macht das so lange, bis der Rest 0 ist, also wenn 250 geteilt durch 250 gleich 1 ergibt und kein Rest übrig bleibt
		if (position_schr_y==0)						// Wenn y-Koordinate = 250, wird die Drehrichtung des Motors der y-Achse umgedreht (Falsch zuvor: DIR-Pin an H_Brücke wird getogglet)
		{
			HAL_GPIO_TogglePin(GPIOB, GPIO_PIN_5);
		}
		flag_schr_y = 0;						// Flag wird wieder auf 0 gesetzt, dadurch kann sich y-Motor erstmal nicht bewegen
	}
}
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
int main(void)
{
	/* MCU Configuration--------------------------------------------------------*/

	/* Reset of all peripherals, Initializes the Flash interface and the Systick. */
	HAL_Init();

	/* Configure the system clock */
	SystemClock_Config();

	/* Initialize all configured peripherals */
	MX_GPIO_Init();
	MX_ADC1_Init();
	MX_ADC2_Init();
	MX_ADC3_Init();
	MX_ADC4_Init();
	MX_I2C1_Init();
	MX_TIM1_Init();
	MX_TIM2_Init();
	MX_TIM3_Init();
	MX_TIM4_Init();
	MX_TIM15_Init();
	MX_TIM16_Init();
	MX_USART2_UART_Init();
	MX_TIM7_Init();
	MX_TIM6_Init();
	MX_TIM8_Init();
	MX_TIM17_Init();
	MX_DMA_Init();
	/* Infinite loop */
	/* USER CODE BEGIN WHILE */
	while (1)  						// Hier beginnt Hauptprogramm:
	{
		/* USER CODE END WHILE */

		/* USER CODE BEGIN 3 */
		/******************************************************************
		 * *************************User_State_Machine**********************
		 * ****************************************************************/
		/**************************State Machine Function************************************************/

		void state_machine()
		{
			States_t State_Manager = Start;

			switch(State_Manager)
			{

			case Start:

				while (Doorgetstate() == 0)				// Erfüllt, wenn Türe noch offen ist
				{
					Laser_switch_state(0);				// Mach Laser aus

					if (ref_z == 0)						// und noch keine Referenzfahrt erledigt ist
					{
						home_z_achse();					// Dann home mal die z-Achse
					}
					Zebene_runter();					// Fahr eine Schicht runter pro druck auf taster
					lcd_print_state_cmd();				//Display function for start drucker
				}

				State_Manager = Init;
				break;

				// nachdem z-Achse ajustiert ist und Türe jz geschlossen wird und start taster gedruckt ist
				while ((Doorgetstate() == 1) && (Start_Taster_getstate() == 1))
				{
			case Init:
				lcd_clear();					//Clear display
				lcd_print_temp_cmd();			//function display to initialise and heat polymer
				Init_Drucker();					// ruf function init drucker
				lcd_clear();					//Clear display
				Temperature_print();			// show current temparture
				if (Polymerready == 1)			// check if polymer 60 grad erreicht hat
					State_Manager = Drucken;	//switch zum drucken
				break;
			case Drucken:
				lcd_clear();					//Clear display
				Schrittmotor_y_achse_bewegen();	// y verfahren
				Z_Achse_ebene_sinken();			// eben sinken
				Show_temp_Freq_Time_Layer();	//show all parameter drucker temperatur, frequnz, remain tme and ebene
				State_Manager = Ende;
				break;
			case Ende:
				if (Anzahl_Ebenen ==250)		// Wenn gedruckt und Anzahl Ebenen 250 erreicht hat, dann
				{
					schwinger_stop();				// Mach Schwinger aus
					lcd_clear();					//Clear display
					lcd_print_End_cmd();			//show Fertig display
				}
				State_Manager = Start;				//spring wieder in case start
				break;
				}
			}
		}

	}


	/******************************while/if Abfrage programm Ablauf(ohne state machine)******************************
		while (Doorgetstate() == 0)					// Erfüllt, wenn Türe noch offen ist (wichtig, da z-Achse ja noch justiert werden muss)
		{
			if (ref_z == 0)						// und noch keine Referenzfahrt erledigt ist
			{
				home_z_achse();					// Dann home mal die z-Achse
			}
			Zebene_runter();					// Fahr eine Schicht runter pro druck auf taster
		}


		while (Doorgetstate() == 1)					// Wenn z-Achse ajustiert ist und Türe jz geschlossen wird
		{
			if ((Start_Taster_getstate() == 1) && (Init ==0))	// Wenn dann auch Start-Taster gedrückt wird UND drucker aktoren nicht init
			{
				Laser_switch_state(0);				// Mach Laser aus

				Init_Drucker();					// ruf function init drucker
				Init = 1;					// Setze Init auf 1
				Start_Taster_gedruckt = 0;			// Setze Variable von Taster gedrückt wieder auf 0
			}
			if ((Init == 1) && (Doorgetstate() == 1))		// Wenn jetzt Türe zu ist und bereits z-Achse initialisert
			{

				Schrittmotor_y_achse_bewegen();			// y verfahren
				Z_Achse_ebene_sinken();				// eben sinken
				frequency_print();				// display Ausgabe
				Drucken = 1;
			}
			if ((Drucken ==1)&& (Anzahl_Ebenen ==50))		// Wenn gedruckt und Anzahl Ebenen 50 erreicht hat, dann
			{
				schwinger_stop();				// Mach Schwinger aus
				Init = 0;
				Ende = 1;					// Setz Variable Ende auf 1
			}
		}
	 */
	/* USER CODE END 3 */
}

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
/* USER CODE BEGIN 4 */

/******************************************************************
 * *************************User_Interrupts**********************
 * ****************************************************************/
/******************************Sinus_erzeugung_interrupt**************************************/

void HAL_TIM_PeriodElapsedCallback (TIM_HandleTypeDef *ht) 		// Funktion zum Abschreiben der Sinustabelle per Timerinterrupt
{
	if (ht == &htim6)						// wenn timer is timer 6 dann
	{
		zaehler++;						// Bei jedem Interrupt geht der Sinus-Wert-Zähler +1 hoch..
		int position = zaehler%128;				// Teile aktuelle Position durch 128 und gibt Rest aus
		if (position==0)					// Wenn bei Division durch 128 kein rest bleibt (eben wenn Zähler selbst 128), dann wieder postion gleich null, sprich sinus ist 0
		{							// Wenn 128 erreicht wird hier dann Drehrichtung der H-Brücke geändert
			HAL_GPIO_TogglePin(GPIOC, GPIO_PIN_1);		// DIR-Pin an H_Brücke wird getogglet

		}


		__HAL_TIM_SET_COMPARE(&htim1, TIM_CHANNEL_1, sinus[position]*3599*kdc);		//setze neu duty cycle wert in CCR mit ARR=3599
	}

	/******************************Drucken_Agorithmus**************************************/

	if ((ht == &htim3) &&(flag_schr_z == 0)) //&&		//wenn Timer is timer 3 auslöst (und z nicht in bewegvorgang ist) dann anfang belichten
	{
		if (Anzahl_Schwingung >= 20)			//Sind bereits mehr als 20 Schwingungen durchgeführt?
		{

			zaehler_X++;				// Setze zaehler_X um eins nach oben: zaehler_x ist aktuelle x-Koordinate
			zaehler_X = zaehler_X%266;		// Teile aktuelle x-Koordinate durch 266: 250+16 alls offset
			__HAL_TIM_SET_COUNTER(&htim3,0);	// Setze Counter 3 zurück
			if (zaehler_X==0)			// Wenn "zaehler_X = zaehler_X%266;" gleich 0 ist
				// (also Schwinger in Schwingung alle x-Koordinaten durchlaufen hat), dann {...}				/
			{
				HAL_TIM_Base_Stop_IT (&htim3);	// Dann stoppe TIM_3 per Interrupt

				zaehler_Y++;			// Wenn die Schwingung alle x-Koordinaten in einer Schwingung durch hat,
				// dann setze y-Koordinate um +1 höher
				zaehler_Y = zaehler_Y%250;	// Kontrolliere ob in y-Koordinate schon alle 250 Koordinaten durchlaufen sind
				// (Ablauf: Teile aktuellen Wert durch 250 und verwende den Rest %)
				if (zaehler_Y==0)		// Wenn aktuelle y-koordinate durch /250 keinen Rest ergibt (also wenn wir auf y = 250 stehen)
				{
					flag_schr_z = 1; 	// hier: Ebene absenken oder für kreis. "flag_schr_z" bedeutet, dass als nächstes der z-Motor verfahren wird
					// und so lange keine Belichtung stattfinden kann.
					// dann z-Achse_ebene_sinken();
				}
			}

			/********************************Belichten************************************/
			if (zaehler_X >= 15)			// Wenn 15 Felder auf x-Koordinate durchlaufen sind (also 15 Interrupts ausgelöst haben), dann:
			{
				dx = (zaehler_X-15-xm);		// Berechne den Abstand (dx) der aktuellen x-Position (zaehler_x) zum Mittelpunkt (xm)
				// und ziehe dann 15 davon ab. Sinn: Druckfeld eingrenzen, sodass die ersten 15 Interrupts keinen Laser auslösen
				dy = (zaehler_Y-ym);				// abstand dy ergibt sich aus aktuellen zahler - y mittelwert
				dxy = sqrtf((dx*dx)+(dy*dy));		//Satz pythagoras a^{2}+b^{2}=c^{2} ==>c={\sqrt {a^{2}+b^{2}}}.
			}
			if ((dxy <= 125)&&(dxy >= 75)) //Wandstarke der Ring: bereich wozum belichtem soll 125 -75 = 50
			{
				Laser_switch_state(1);			//laser on
			}
			else							//wenn außerhalb des bereich ist
			{
				Laser_switch_state(0);
			}
		}
	}
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

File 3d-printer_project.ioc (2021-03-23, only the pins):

Mcu.UserName=STM32F303RETx
PA0.GPIO_Label=Laser
PA0.Signal=GPIO_Output
PA1.GPIO_Label=TEST-I-Regler 
PA1.Signal=ADC1_IN2
PA11.GPIO_Label=LICHTSCHRANKE
PA11.Signal=S_TIM4_CH1
PA13.GPIO_Label=TMS
PA13.Signal=SYS_JTMS-SWDIO
PA14.GPIO_Label=TCK
PA14.Signal=SYS_JTCK-SWCLK
PA2.GPIO_Label=USART_TX
PA2.Signal=USART2_TX
PA3.GPIO_Label=USART_RX
PA3.Signal=USART2_RX
PA4.GPIO_Label=TEST-P-REGLER 
PA4.Signal=ADC2_IN1
PA5.GPIO_Label=LD2 [Green Led]
PA5.Signal=GPIO_Output
PA6.GPIO_Label=LED-ROT 
PA6.Signal=GPIO_Output
PA7.GPIO_Label=LED-GELB 
PA7.Signal=GPIO_Output
PA8.GPIO_Label=SLEEP1_Z 
PA8.Signal=GPIO_Output
PB0.GPIO_Label=DAC-MESSPIN 
PB0.Signal=GPIO_Analog
PB1.Signal=ADC3_IN1
PB10.GPIO_Label=TASTER3_PAUSE 
PB10.Signal=GPXTI10
PB11.GPIO_Label=T\u00DCR_SCHALTER 
PB11.Signal=GPXTI11
PB12.GPIO_Label=TASTER1_START 
PB12.Signal=GPXTI12
PB14.GPIO_Label=HEIZUNG-PWM
PB14.Signal=S_TIM15_CH1
PB15.GPIO_Label=TEMP-Mess
PB15.Signal=ADC4_IN5
PB2.GPIO_Label=ENDLAGE_Z 
PB2.Signal=GPIO_Input
PB3.GPIO_Label=SWO
PB3.Signal=SYS_JTDO-TRACESWO
PB4.GPIO_Label=STEP2_Y
PB4.Signal=GPIO_Output
PB5.GPIO_Label=DIR2_Y 
PB5.Signal=GPIO_Output
PB6.GPIO_Label=ENA2_Y 
PB6.Signal=GPIO_Output
PB7.GPIO_Label=RESET2_Y 
PB7.Signal=GPIO_Output
PB8.GPIO_Label=SCL  
PB8.Signal=I2C1_SCL
PB9.GPIO_Label=SDA 
PB9.Signal=I2C1_SDA
PC0.GPIO_Label=PWM-H 
PC0.Signal=S_TIM1_CH1
PC1.GPIO_Label=DIR-H 
PC1.Signal=GPIO_Output
PC10.GPIO_Label=Extra
PC10.Signal=GPIO_Output
PC13.GPIO_Label=Blue_pushbutton
PC13.Signal=GPXTI13
PC14-OSC32_IN.Signal=RCC_OSC32_IN
PC15-OSC32_OUT.Signal=RCC_OSC32_OUT
PC2.GPIO_Label=DIS-H 
PC2.Signal=GPIO_Output
PC3.GPIO_Label=SO-H 
PC3.Signal=GPIO_Output
PC4.GPIO_Label=LED-GR\u00DCN 
PC4.Signal=GPIO_Output
PC5.GPIO_Label=ENDLAGE_Y 
PC5.Signal=GPIO_Input
PC6.GPIO_Label=STEP1_Z
PC6.Signal=GPIO_Output
PC7.GPIO_Label=DIR1_Z 
PC7.Signal=GPIO_Output
PC8.GPIO_Label=ENA1_Z 
PC8.Signal=GPIO_Output
PC9.GPIO_Label=RESET1_Z 
PC9.Signal=GPIO_Output
PD2.GPIO_Label=SLEEP2_Y 
PD2.Signal=GPIO_Output
PF0-OSC_IN.Signal=RCC_OSC_IN
PF1-OSC_OUT.Signal=RCC_OSC_OUT

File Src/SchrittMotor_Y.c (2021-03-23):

/*
 * SchrittMotor_Y.c
 *
 *  Created on: 10.12.2019
 *      Author: Sami
 */

#include "SchrittMotor_Y.h"
/* Schrittmotor Y_achse */

void Stepper_Y_Achse(void){

	// Initialisierung Y_achse

	HAL_GPIO_WritePin(GPIOB, GPIO_PIN_7, GPIO_PIN_SET);				// Reset (inverted) PIN
	HAL_GPIO_WritePin(GPIOD, GPIO_PIN_2, GPIO_PIN_SET);				// Sleep (inverted) PIN
	HAL_GPIO_WritePin(GPIOB, GPIO_PIN_6, GPIO_PIN_RESET); 			// Enable (inverted) PIN

	// Rotation Schleife Y_achse
	HAL_GPIO_WritePin(GPIOB, GPIO_PIN_5,SET);   			//  Direction Pin (+sense rotation)

	for(int i=0; i<200; i++)				// 200schritte = 360°
	{
		HAL_GPIO_WritePin(GPIOB, GPIO_PIN_4, GPIO_PIN_SET);	// STEP PIN High
		HAL_Delay(1); //1ms
		HAL_GPIO_WritePin(GPIOB, GPIO_PIN_4, GPIO_PIN_RESET);	// STEP PIN Low
		HAL_Delay(1);
	}
	HAL_Delay(2000);

	HAL_GPIO_WritePin(GPIOB, GPIO_PIN_5,RESET);			//  Direction Pin (-sense rotation)

	for(int j=0; j < 200; j++)
	{
		HAL_GPIO_WritePin(GPIOB, GPIO_PIN_4, GPIO_PIN_SET);
		HAL_Delay(1);
		HAL_GPIO_WritePin(GPIOB, GPIO_PIN_4, GPIO_PIN_RESET);
		HAL_Delay(1);
	}
	HAL_Delay(2000);
}

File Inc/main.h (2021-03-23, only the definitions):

#define Blue_pushbutton_Pin GPIO_PIN_13
#define Blue_pushbutton_GPIO_Port GPIOC
#define Blue_pushbutton_EXTI_IRQn EXTI15_10_IRQn
#define PWM_H_Pin GPIO_PIN_0
#define PWM_H_GPIO_Port GPIOC
#define DIR_H_Pin GPIO_PIN_1
#define DIR_H_GPIO_Port GPIOC
#define DIS_H_Pin GPIO_PIN_2
#define DIS_H_GPIO_Port GPIOC
#define SO_H_Pin GPIO_PIN_3
#define SO_H_GPIO_Port GPIOC
#define Laser_Pin GPIO_PIN_0
#define Laser_GPIO_Port GPIOA
#define TEST_I_Regler_Pin GPIO_PIN_1
#define TEST_I_Regler_GPIO_Port GPIOA
#define USART_TX_Pin GPIO_PIN_2
#define USART_TX_GPIO_Port GPIOA
#define USART_RX_Pin GPIO_PIN_3
#define USART_RX_GPIO_Port GPIOA
#define TEST_P_REGLER_Pin GPIO_PIN_4
#define TEST_P_REGLER_GPIO_Port GPIOA
#define LD2_Pin GPIO_PIN_5
#define LD2_GPIO_Port GPIOA
#define LED_ROT_Pin GPIO_PIN_6
#define LED_ROT_GPIO_Port GPIOA
#define LED_GELB_Pin GPIO_PIN_7
#define LED_GELB_GPIO_Port GPIOA
#define LED_GR_N_Pin GPIO_PIN_4
#define LED_GR_N_GPIO_Port GPIOC
#define ENDLAGE_Y_Pin GPIO_PIN_5
#define ENDLAGE_Y_GPIO_Port GPIOC
#define DAC_MESSPIN_Pin GPIO_PIN_0
#define DAC_MESSPIN_GPIO_Port GPIOB
#define ENDLAGE_Z_Pin GPIO_PIN_2
#define ENDLAGE_Z_GPIO_Port GPIOB
#define TASTER3_PAUSE_Pin GPIO_PIN_10
#define TASTER3_PAUSE_GPIO_Port GPIOB
#define TASTER3_PAUSE_EXTI_IRQn EXTI15_10_IRQn
#define T_R_SCHALTER_Pin GPIO_PIN_11
#define T_R_SCHALTER_GPIO_Port GPIOB
#define T_R_SCHALTER_EXTI_IRQn EXTI15_10_IRQn
#define TASTER1_START_Pin GPIO_PIN_12
#define TASTER1_START_GPIO_Port GPIOB
#define TASTER1_START_EXTI_IRQn EXTI15_10_IRQn
#define HEIZUNG_PWM_Pin GPIO_PIN_14
#define HEIZUNG_PWM_GPIO_Port GPIOB
#define TEMP_Mess_Pin GPIO_PIN_15
#define TEMP_Mess_GPIO_Port GPIOB
#define STEP1_Z_Pin GPIO_PIN_6
#define STEP1_Z_GPIO_Port GPIOC
#define DIR1_Z_Pin GPIO_PIN_7
#define DIR1_Z_GPIO_Port GPIOC
#define ENA1_Z_Pin GPIO_PIN_8
#define ENA1_Z_GPIO_Port GPIOC
#define RESET1_Z_Pin GPIO_PIN_9
#define RESET1_Z_GPIO_Port GPIOC
#define SLEEP1_Z_Pin GPIO_PIN_8
#define SLEEP1_Z_GPIO_Port GPIOA
#define LICHTSCHRANKE_Pin GPIO_PIN_11
#define LICHTSCHRANKE_GPIO_Port GPIOA
#define TMS_Pin GPIO_PIN_13
#define TMS_GPIO_Port GPIOA
#define TCK_Pin GPIO_PIN_14
#define TCK_GPIO_Port GPIOA
#define Extra_Pin GPIO_PIN_10
#define Extra_GPIO_Port GPIOC
#define SLEEP2_Y_Pin GPIO_PIN_2
#define SLEEP2_Y_GPIO_Port GPIOD
#define SWO_Pin GPIO_PIN_3
#define SWO_GPIO_Port GPIOB
#define STEP2_Y_Pin GPIO_PIN_4
#define STEP2_Y_GPIO_Port GPIOB
#define DIR2_Y_Pin GPIO_PIN_5
#define DIR2_Y_GPIO_Port GPIOB
#define ENA2_Y_Pin GPIO_PIN_6
#define ENA2_Y_GPIO_Port GPIOB
#define RESET2_Y_Pin GPIO_PIN_7
#define RESET2_Y_GPIO_Port GPIOB
#define SCL_Pin GPIO_PIN_8
#define SCL_GPIO_Port GPIOB
#define SDA_Pin GPIO_PIN_9
#define SDA_GPIO_Port GPIOB

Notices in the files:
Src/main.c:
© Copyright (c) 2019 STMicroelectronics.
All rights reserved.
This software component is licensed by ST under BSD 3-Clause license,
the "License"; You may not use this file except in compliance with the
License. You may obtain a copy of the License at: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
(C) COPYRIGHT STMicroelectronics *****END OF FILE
